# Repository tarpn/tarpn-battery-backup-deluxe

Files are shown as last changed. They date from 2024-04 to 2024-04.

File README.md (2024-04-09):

# TARPN Battery Backup Deluxe

An open source DC-DC Uninterrupted Power Supply for TARPN. 

📖 Click here for [Operation Manual](https://github.com/tarpn/tarpn-battery-backup-deluxe/wiki/Operation-Manual) 📖

Battery Backup Deluxe (BBD) is a system that monitors and switches DC power between a 
power supply and a battery. It is a bespoke power management solution for multi-port packet
radio nodes in the [TARPN project](http://tarpn.net). It is also generally useful for any 12V
systems including non-TARPN Amateur Radio activities.

Supported Features:
* High current capability (30A continuous)
* Automatic switchover to battery
* Battery protection (low/high voltage cutoff)
* Over-temperature cutoff
* Separate switching of critical loads power for priority devices (3A max)
* Safe shutdown procedure of RaspberryPi

Experimental Features:
* Battery charging

Non-Features:
* Load distribution or fusing
* Integration with battery chargers (AC/DC chargers, or solar charge controllers)

Two custom PCBs are employed for voltage sensing, switching, and control. The two boards are
referred to as the Power Board and the Control Board. The Power Board connects to a regulated
DC power supply, a 12V battery, a 12V load, a DC buck regulator for a RaspberryPi, and the Control Board. 
The Control Board connects to a RaspberryPi using a communication cable. 

# Images

Power Board, bare PCB
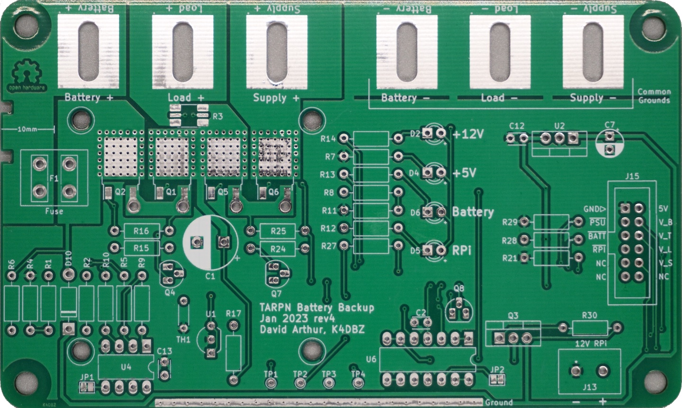
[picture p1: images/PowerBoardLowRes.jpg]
Power Board PCB


Power Board, assembled and installed



# PCB Overview

Power board layout

```
 -[B]--[L]--[S]--[N]--[N]--[N]-
|  |    |    |                 |
|  |~S2~ ~S1~               [C]|
|  |                           |
|   ~ ~ ~ ~ ~ ~ ~ ~ ~ ~ S3     |
|                        |     |
 -----------------------[P][N]-
```

Labels:

* B: Battery Positive
* S: Supply Positive
* L: Load Positive
* N: Common Grounds
* P: Critical Load Positive
* S1: Supply Switch
* S2: Battery Switch
* S3: Critical Load Switch
* C: 12-pin connector to control board

Three p-channel mosfet switches are utilized to connect various loads to one of two DC power sources. 
Loads connected to the "L" terminal are either connected to the Power Supply "S" via S1, the Battery 
"B" via S2, or they are disconnected. A separate low power switch S3 is used for critical loads, 
such as a RaspberryPi or other low power control circuits.

S1 and S2 are high powered DPAK mosfets with a very low on-resistance.

All connected supplies and loads share a common ground. This ground is also shared with the control board. 
If a RaspberryPi (or other device) is monitoring the serial output of the control board, it must also share
this common ground.

Control board layout

```
 ------------------------------
|         ___________      ___  |
|[C]     |   OLED    |    | R | |
|         -----------      ---  |
|    [RPi]               [ICSP] |
 ------------------------------
```

Labels:

* C: 12-pin connector to power board
* RPi: 10-pin connector to Raspberry Pi
* ICSP: Programming header for ATMega
* OLED: 128x32 OLED display
* R: Rotary encoder with switch

# Control Board Modes

The digital electronics on the power board, the 5V regulator for the Control Board, and the critical load
output are powered directly by the battery. 

## Standby

When a power supply is attached and supplying a sufficient voltage, the system will be in Standby mode. 
Loads are powered by the power supply through S1.

* S1: closed
* S2: open
* S3: closed

## Backup

If a low voltage is detected on the power supply, the loads are transferred to the battery. This switching
time is typically in the microsecond range. The ability of the loads to maintain sufficient voltage during
the switching time is dependent on the load current and the available standby capacitance. 
C1 on the power board can be populated with a reasonably large (1000µF range) bulk capacitor. 

* S1: open 
* S2: closed
* S3: closed

## Recovery

Once in the Backup state, the system will enter the Recovery state if a sufficient voltage is seen at the
power supply input. To avoid oscillations, the system will remain in the Recovery state for a configured
number of milliseconds before transitioning to Standby.

* S1: open 
* S2: closed
* S3: closed

## Faults

The system monitors battery voltage to protect the loads from over-voltage and to protect the battery from
under-voltage. In these two cases, the battery is disconnected from the loads.

A temperature sensor is used to monitor the temperature of the PCB near the mosfet switches. If a high
temperature is detected, the switches are both opened to prevent the mosfets from over-heating and failing.

* S1: open 
* S2: open
* S3: closed

# Tuning

To account for variability of components used by the sensor circuits, the firmware includes several "tunables".

* X1: Current Sense. A scaling factor for the current shunt resistor R3. It should be set to 0.04 (20 * R3)
* X2: Current Offset. A voltage offset provided by the reference voltage U1. It should be set to 2.486
* X3: ADC Reference. A voltage reference provided by U5. Measured from AREF (typically 4.860)
* X4: Voltage Factor. A scaling factor for the two resistor divider networks R1+R4 and R8+R11. It should be set to R4 / (R1 + R4).
* X5: Voltage Offset. A voltage offset for the resistor divider networks. Set this to 0.0
* X6: Battery Factor. The same as X1, but for R36 (this may be deprecated in the future)
* X7: Battery Offset. The same as X2, but for the battery current shunt (this may be deprecated in the future)

# Configuration

TODO

# RaspberryPi Interface

J8 on the control board connects to pins 1 through 10 on the RaspberryPi. 

| Pin | RPi signal | Control board signal |
| --- | --- | --- |
| 1 | +3V3 | used for pullup of pin 5 |
| 2 | +5V | unused |
| 3 | GPIO 2 | RPI_PWR (active low) |
| 4 | +5V | unused |
| 5 | GPIO 3 | RPI_SHUTDOWN (active low) |
| 6 | Ground | Ground |
| 7 | GPIO 4 | Reset† |
| 8 | GPIO 14 | RXD (serial) |
| 9 | Ground | Ground |
| 10  | GPIO 15 | TXD (serial) |

† This pin is sometimes cut on older TARPN installations. See below for workaround instructions.

The RPI_SHUTDOWN signal is used to trigger a shutdown of the RPi. When this signal is momentarily pulled low the RPi 
will perform a safe shutdown. A pull-up resistor between RPi pin 5 and RPi pin 1 is used to prevent this
signal from floating.

The RPI_PWR is used to inform the control board whether or not the RPi has power. When this signal is
low, the RPi is powered on. This signal allows the control board to determine when the RPi has powered off 
following a safe shutdown.

RXD and TXD are used for serial communication from the control board to the RPi. This is used for exporting
telemetry from the control board.

If pin 7 has been cut, a separate jumper between an unused GPIO on the RPi and the RESET line on the control 
board will be needed. Pin 5 of the ISCP header can be used to solder one end of a jumper. When doing firmware
uploads from the RPi, a different reset pin can be selected with the `--gpio` argument.

## RPi Hardware Modification

To accommodate the 10 pin ribbon connector on the RPi, pins 11 and 12 must be snipped or bent out of the way.



## RPi Hardware Configuration

To enable the functions of RPI_SHUTDOWN and RPI_PWR, two special configurations are needed on the RPi.
In the `/boot/config.txt` file, add the following lines below the comment 
`# Additional overlays and parameters are documented /boot/overlays/README`:

```
dtoverlay=gpio-poweroff,gpiopin=2,active_low=1
dtoverlay=gpio-shutdown,gpio_pin=3,active_low=1,gpio_pull=up
```

The hardward UART must also be enabled for communication with the control board. At the bottom of `/boot/config.txt`, add

```
[all]
enable_uart=1
```

This can be done when preparing the SD card or on a running RPi. If done on a running RPi, a reboot is necessary for the 
changes to take affect.

## RPi Software Setup

Assuming a starting point of Raspberry Pi OS (Debian Bullseye or Bookworm), we need to install a few dependencies.

```
sudo apt-get -y install python3-pip python3-venv supervisor prometheus prometheus-node-exporter lsof avrdude
```

Configure supervisor to be run as the "pi" user. Modify the file `/etc/supervisor/supervisord.conf` to add a "chown"
to the "unix_http_server" section:

```
[unix_http_server]
file=/var/run/supervisor.sock   ; (the path to the socket file)
chmod=0700                      ; sockef file mode (default 0700)
chown=pi:pi                     
```

Restart supervisor service
```
sudo service supervisor restart
```

Confirm supervisor is running and accessible

```
supervisorctl pid
```

Should return the PID (Process ID) of the supervisord program.

### Install tarpn-bbd Python package

Create an installation directory under `/opt` and install a Python environment into it.

_These instructions assume an installation directory of /opt/tarpn. However, the software can be installed at any location_

```
sudo mkdir /opt/tarpn
sudo chown pi:pi /opt/tarpn
python3 -m venv /opt/tarpn
```

Install the `tarpn-bbd-agent` program into the newly created Python environment

```
/opt/tarpn/bin/pip install --upgrade --index-url https://pypi.mumrah.synology.me/simple tarpn-bbd-agent
```

This will install the program and create several directories under `/opt/tarpn`. 

### Configure Supervisor

Once the tarpn-bbd Python package is installed, we can copy a supervisor config into the system's
configuration directory. This will allow for the Python program to be automatically run on RPi startup
and automatically restarted if it encounters a fatal error.

```
sudo cp /opt/tarpn/extra/tarpn-bbd-agent-supervisor.conf /etc/supervisor/conf.d/tarpn-bbd-agent.conf
```

This file tells supervisor how to run the tarpn-bbd-agent program. Issue a "reload" command to tell
supervisor to read this new config file

```
supervisorctl reload
```

Now the agent program should be running. Run "supervisorctl status" to confirm. The output should look like:

```
> supervisorctl status
tarpn-bbd-agent                  RUNNING   pid 15487, uptime 0:00:04
```

Check that the metrics are being exposed over HTTP. Visit http://localhost:9000 on the RPi, or http://<your-rpi-ip-address>:9000
from another computer on your network. You should see a plain text output that looks like:

```
# HELP python_gc_objects_collected_total Objects collected during gc
# TYPE python_gc_objects_collected_total counter
python_gc_objects_collected_total{generation="0"} 327.0
python_gc_objects_collected_total{generation="1"} 81.0
python_gc_objects_collected_total{generation="2"} 0.0
```

Next, check that the node metrics are being exposed by the prometheus-node-exporter. Visit http://localhost:9100
or http://<your-rpi-ip-address>:9100. This will have a lot more output than the other exporter. Here is a snippet

```
# HELP node_cpu_seconds_total Seconds the CPUs spent in each mode.
# TYPE node_cpu_seconds_total counter
node_cpu_seconds_total{cpu="0",mode="idle"} 2883.87
node_cpu_seconds_total{cpu="0",mode="iowait"} 5.04
node_cpu_seconds_total{cpu="0",mode="irq"} 0
node_cpu_seconds_total{cpu="0",mode="nice"} 0
node_cpu_seconds_total{cpu="0",mode="softirq"} 0.95
node_cpu_seconds_total{cpu="0",mode="steal"} 0t
node_cpu_seconds_total{cpu="0",mode="system"} 11.35
node_cpu_seconds_total{cpu="0",mode="user"} 22.08
```

### Python Configuration

The default configuration should work on most installations, but if a different serial port or HTTP port is needed, 
it can be changed in `/opt/tarpn/config/bbd.ini`

```
[default]
log.dir = /opt/tarpn/logs
log.config = config/logging.ini
serial.port = /dev/ttyS0
serial.speed = 38400
prometheus.port = 9000
```

After re-configuring, restart the service with supervisor

```
supervisorctl restart tarpn-bbd-agent
```

# Monitoring

If desired, a metrics collection database (Prometheus) and dashboard system (Grafana) can be used to visualize
the sensor data exported by the control board.

Prometheus needs network access to the RPi running `tarpn-bbd`, and Grafana needs network access to Prometheus.
On a home network, this is usually achieved without any extra effort. It is possible to run the TARPN stack 
(including `tarpn-bbd`) along with Prometheus and Grafana, but it is also possible to run Prometheus and Grafana
on a separate server if resources of the RPi become constained.

## Prometheus Configuration

Prometheus is an efficient time-series database that is optimized for metrics collection. By default, Prometheus 
is installed on the RPi that is also running TARPN and the Python agent. If desired, Prometheus can also be 
installed on another server (RPi or otherwise). Follow the 
[general installation instructions](https://prometheus.io/docs/prometheus/latest/installation/) for this.

Put the prometheus config in place

```
sudo cp /opt/tarpn/extra/prometheus.yml /etc/prometheus/prometheus.yml
```

And restart prometheus

```
sudo service prometheus restart
```

Launch the Prometheus UI and confirm the three targets are "UP". Load the UI by accessing http://localhost:9090 
on a web browser on the RPi, or http://<your-rpi-ip-address>:9090 from a web browser on another computer in your
network.

Click on Status, then Targets



And the three Targets should be in the "UP" State.



## Grafana Install and Configuration

Follow the instructions to [install Grafana OSS](https://grafana.com/tutorials/install-grafana-on-raspberry-pi/#install-grafana).
Grafana can run on the TARPN RPi or on a separate server (RPi or otherwise).

For other installation types, follow the [general installation instructions](https://grafana.com/docs/grafana/latest/setup-grafana/installation/).

Copy some configuration files from the `tarpn-bbd` installation over to Grafana

```
sudo cp /opt/tarpn/extra/grafana.ini /etc/grafana/grafana.ini
sudo cp /opt/tarpn/extra/prometheus-datasource.yml /etc/grafana/provisioning/datasources/prometheus.yml
```

Enable Grafana service (as indicated the Grafana installation output). This will enable Grafana to start
when the RPi starts.

```
sudo /bin/systemctl daemon-reload
sudo /bin/systemctl enable grafana-server
```

Start Grafana (restart if it's already running)
```
sudo service grafana restart
```

Access the Grafana UI at http://localhost:3000 or `http://<your-rpi-ip-address>:3000`. 



Confirm the "prometheus" datasource was created

https://github.com/tarpn/tarpn-battery-backup-deluxe/assets/55116/4cb37a2d-a11b-4c16-b97d-481c0bf3d614

Next, import the dashboard

* Open https://github.com/tarpn/tarpn-battery-backup-deluxe/blob/main/py/extra/grafana-dashboard.json
* Click "Download Raw File"
* Open Grafana UI
* Navigate to Dashboards
* Click New -> Import
* Select the dashboard JSON file
* Select the "Prometheus" datasource we looked at earlier

https://github.com/tarpn/tarpn-battery-backup-deluxe/assets/55116/16305afa-259e-4ca9-8b7f-3a017b2bc0ff

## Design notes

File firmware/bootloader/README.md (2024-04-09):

Built from optiboot at revision 55d1e6b36922

```
make clean AVR_FREQ=8000000 BAUD_RATE=38400 LED=D7 LED_START_FLASHES=3 LED_DATA_FLASH=1 UART=0 TIMEOUT=4 atmega328
```

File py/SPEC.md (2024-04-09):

Serial data specification for BBD firmware

v1 Sep 14, 2023
===============

On firmware startup, the string "START" is sent followed by a newline.

Subsequently, every 2 seconds or when a event occurs, the firmware will send data in the 
following BNF form:

```
<line>		::= <state> <ws> "Battery=" <float> <ws> "Supply=" <float> <ws> "RPiOn=" <bool> <ws> "StateTime=" <long> <ws> "UpTime=" <long> <ws> "DT=" <long> <ws> "Git=" <str> [<cont>] <nl>
<ws>		::= " " [<ws>]	; any amount of whitespace characters
<nl>		::= "\n"	; newline character
<float>		::= <digits> "." <digits>
<long>		::= <digits>
<bool>		::= "1" | "0"
<str>		::= <letter> [<str>]
<digits>	::= <digit> [<digits>]
<state>		::= "Null" | "Initializing" | "Standby" | "Backup" | "Recovery" | "BatteryLow" | "BatteryLowTrip" | "BatteryHigh" | "BatteryHighTrip" | "OverTemp" | "OverTempRecovery" | "BeginShutdown" | "RPiShutdown" | "ShutdownComplete"
<cont>		::= <ws> "Temperature=" <float> <ws> "AH=" <float> <ws> "AmpSecDelta=" <float> <ws> "BatteryAmpSec=" <float> <ws> "AmpAvg=" <float> <ws> "AmpMax=" <float> <ws> "WattSecDelta=" <float> "<ws>WattAvg=" <float>
```

v2 Dec 26, 2023
===============

Serial data is ascii text separated by newlines. The first word of a line indicates its type.

Previously, each line was interpreted as metrics data with the exception of a special "START" line. Now, each line 
will begin with its message type allowing for more flexibility in the protocol.

Three types will be defined initially

* `DATA`: a line of key/value data pairs. See format below
* `EVENT <type> [<args>]`: a discrete event that occurred, such as a switch changing states
* `LOG`: informational text sent by the firmware

Also, this version of the protocol introduces bidirectional communication. 

* `P <0|1> <len> <text>`: informational text sent by the PC for display by the OLED. One of two lines is specified followed 
                           by the desired text. Any characters exceeding the width of the display will be truncated
* `H`: a heartbeat, sent periodically to inform the firmware that the PC is alive

Change state strings to be all caps with underscores. This is to align the state with the new UI
for the OLED display.

```
<line>		::= <state> <ws> "Battery=" <float> <ws> "Supply=" <float> <ws> "RPiOn=" <bool> <ws> "StateTime=" <long> <ws> "UpTime=" <long> <ws> "DT=" <long> <ws> "Git=" <str> [<cont>] <nl>
<ws>		::= " " [<ws>]	; any amount of whitespace characters
<nl>		::= "\n"	; newline character
<float>		::= <digits> "." <digits>
<long>		::= <digits>
<bool>		::= "1" | "0"
<str>		::= <letter> [<str>]
<digits>	::= <digit> [<digits>]
<state>		::= "NULL" | "INITIALIZING" | "STANDBY" | "BACKUP" | "RECOVERY" | "BATT_LOW" | "BATT_LOW_TRIP" | "BATT_HIGH" | "BATT_HIGH_TRIP" | "OVER_TEMP" | "OVER_TEMP_RECOVER" | "BEGIN_SHUTDOWN" | "RPI_SHUTDOWN" | "SHUTDOWN_COMPLETE"
<cont>		::= <ws> "Temperature=" <float> <ws> "AH=" <float> <ws> "AmpSecDelta=" <float> <ws> "BatteryAmpSec=" <float> <ws> "AmpAvg=" <float> <ws> "AmpMax=" <float> <ws> "WattSecDelta=" <float> "<ws>WattAvg=" <float>
```

##  Metrics Flow

### Current

Shows "instantaneous" current. 

Prometheus metrics: load_amps, peak_amps

load_amps: Gauge, set by AmpAvg from serial
peak_amps: Gauge, set by AmpMax from serial

AmpAvg is the number of accumulated amp-seconds divided by the reporting period. Amp-seconds are 
continuously integrated whenever the ADC is sampled.

### Power

Shows "instantaneous" power (watts).

Prometheus metric: load_watt, load_watt_sec

load_watt: Gauge, set by WattAvg from serial
load_watt_sec: Counter, incremented by WattSecDelta from serial

WattAvg is accumulated watt-seconds divided by the reporting period. The watt-seconds are
continuous integrated as (current * voltage) whenever the ADC is sampled. This gives more accurate
reading since the voltage can vary based on the current.

WattSecDelta is the number of watt-seconds accumulated during the reporting period.

```
metrics->report->load_amp_sec_delta = (metrics->current_amp_seconds - metrics->report->load_amp_sec);
metrics->report->load_amp_sec = metrics->current_amp_seconds;
metrics->report->load_amp_avg = metrics->report->load_amp_sec_delta / report_period_s;
```

TODO

* Instantaneous Battery Voltage, Current. 
* Instantaneous Load Power (computed based on state)
* Delta of power. Watt*sec since last report. `increase(load_watt_sec_total[1m]) / 60`
* Cumulative power? Watt*sec since startup. Is this useful? Why not just sum the delta

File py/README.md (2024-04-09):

# Python Metrics Scraper

# Installation

## System Requirements

On Linux (including Raspbian) ensure at least Python 3.7 is installed.

```shell
python3 --version
```

Next, install pip, and virtualenv

```shell
sudo apt-get install python3-pip
pip3 install virtualenv
```

On Mac OS:

```shell
brew install python3
pip3 install virtualenv
```

## Install the software (RPi)

Create an installation directory under opt and install a Python environment into it

_These instructions assume an installation directory of /opt/tarpn. However, the software can be installed at any location_

```shell
sudo mkdir /opt/tarpn
sudo chown pi:pi /opt/tarpn
python3 -m venv /opt/tarpn
```

Install a release

```shell
/opt/tarpn/bin/pip install --upgrade --index-url https://pypi.mumrah.synology.me/simple tarpn-bbd-agent
```

## Configuration

A sample config file is provided in /opt/tarpn/config/bdd.ini.sample

```ini
; Do not edit this file. Make a copy named bdd.ini and edit that one.

[default]
log.dir = /opt/tarpn/logs
log.config = config/logging.ini
serial.port = /dev/ttyS0
serial.speed = 38400
prometheus.port = 9000
```

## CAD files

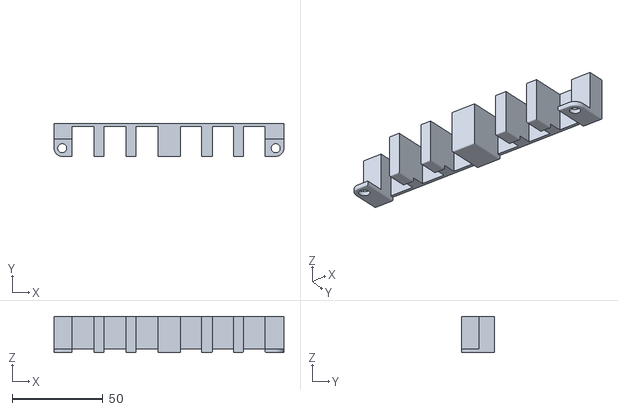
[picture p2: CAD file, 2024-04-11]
3d-models/TerminalGuard.stl
126.4 x 18.0 x 20.0

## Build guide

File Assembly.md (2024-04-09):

# Assembly

Required tools:
* Temperature controlled soldering station (e.g., Hakko FX888D, Weller WLC100)
* Hot air rework station
* Precision tweezers
* Silicone work mat
* Fume extractor (recommended)

Several assembly steps for the Power Board require very high heat. A silicone mat may be required to protect your work surface. 
Be careful handling the PCB in between assembly steps.

The general sequence of assembly for the Power Board is according to height. Shorter parts are assembled first.

* SMD parts 🔥
  * R3
  * Q1, Q2, Q5, Q6
  * Q1 to Q2 jumper (optional)
  * Q5 to Q6 jumper (optional)
* Resistors, diodes, thermistor, ceramic capacitors
* RN1
* U7, U6, U4 (optionally, sockets for each)
* D2, D4, D5, D6 (LEDs)
* TO-92 parts
* J12 (12 pin connector)
* J13 (Terminal screw block)
* 12V fan connector
* C7, C1 (electrolytic capactitors)
* Terminal Lugs 🔥
* F1 connectors 🔥
* U2, Q3 (TO-220)
* Heat sink (optional)

## BOM

The Bill-Of-Materials for Digi-Key is located at this address https://www.digikey.com/en/mylists/list/4BDBKJ7A9E. There are two
optional parts in the BOM (heatsink and push-pins) with quantity zero.

Some additional parts will need to be sourced from other vendors.

* Six (6) Terminal Lugs, part number B6A-PCB-RS from [LugsDirect](https://lugsdirect.com/IHI_HIGH_CURRENT_PCB-TERMINALS-_SELECTION_CHART2.htm)
* i2c 128x32 OLED Display, Amazon/eBay/etc. [Example Amazon Listing](https://www.amazon.com/Pieces-Display-Module-SSD1306-3-3V-5V/dp/B08L7QW7SR) 
* 12 pin rectangular ribbon connector [Example Amazon listing](https://www.amazon.com/gp/product/B07FKPXML5)

Optional parts:
* IC sockets [Example Amazon listing](https://www.amazon.com/Glarks-122Pcs-Sockets-Adaptor-Assortment/dp/B01GOLSUAU)
* 12V fan (in BOM)
* Heatsink (in BOM)
* Large thermal pad for heatsink [Example Amazon listing](https://www.amazon.com/gp/product/B09DC772PR)

## SMD Resistor (R3) soldering

🔥Hot Parts🔥

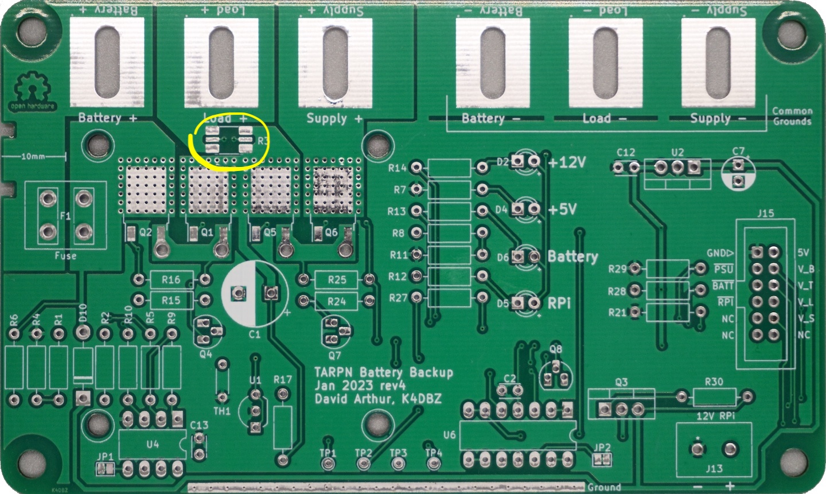
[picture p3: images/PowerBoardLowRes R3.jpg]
R3


This resistor is essentially a chunk of copper with specific dimensions to give a good precision small resistance.
For best results, this part should be soldered to the four pads of the footprint as evenly as possible. For best
results, pre-solder a very small amount of solder to the four pads and clean them with IPA or flux remover. Visually
inspect them to see that they are around the same height. Place the SMD resistor on the pads and apply hot air.

## DPAK soldering

🔥Hot Parts🔥

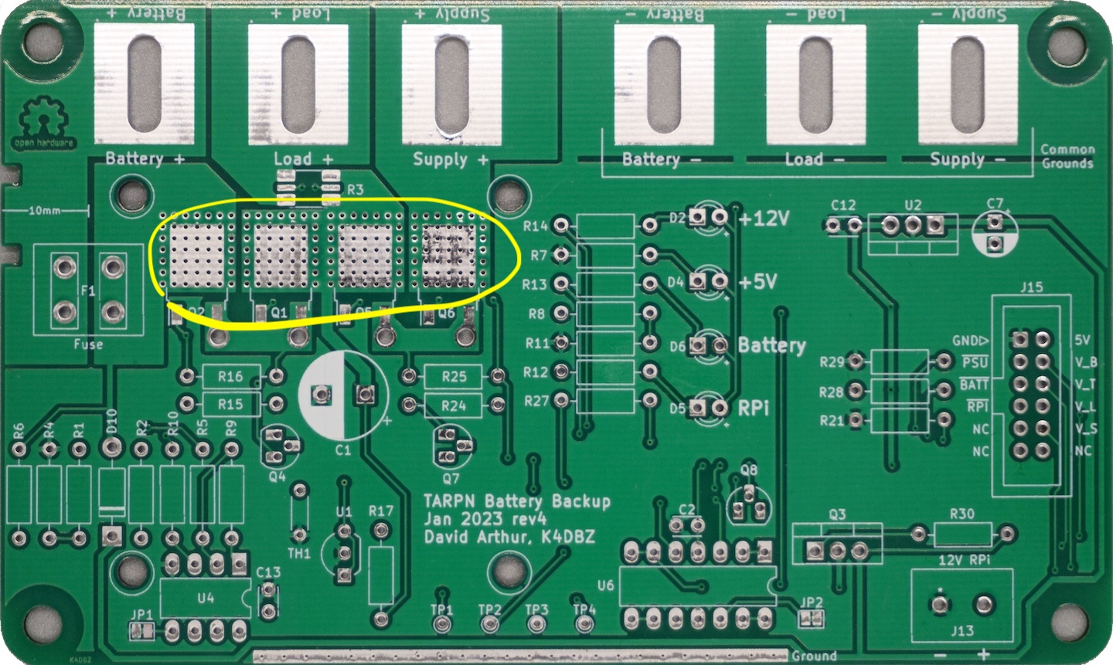
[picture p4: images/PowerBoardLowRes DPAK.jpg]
DPAK Mosfets


The four DPAK mosfet are best soldered with a high temperature (750-800F) iron with a large tip. Hot air can be useful as well.

The big pad should be pre-soldered and cleaned with alcohol or other flux remover. The solder will wick through
the thermal vias during pre-soldering, this is normal. After pre-soldering, apply flux to the pad and solder the
two legs. Once the legs are soldered, begin applying heat to the pad and tab. 

The Power Board has a copper plane on the top and bottom, and the mosfet pads are connected through to the back
with thermal vias. It will take some time for the board to heat up sufficiently for solder to flow. Once the 
existing solder starts to flow, apply fresh solder until adequate fillets are present all around the tab.

## Mosfet jumpers

🔥Hot Parts🔥

Two copper jumpers can be installed to improve the ampacity of the Power Board. A gauge is provided on the edge of the
Power Board to help form the jumpers. The jumper holes are 2.6mm which will accommodate 10 AWG wire. If the jumper is
installed, apply enough solder to create a fillet between the jumper and the mosfet leg.

## Resistors

Some of the resistors on the power board are high precision (0.1%)

* 49.9 kOhm: R1,R6,R8
* 10 kOhm: R2,R4,R9,R11
* 259 Ohm: R5,R10

These are mainly used as high precision voltage divider for accurate sensing of the temperature, voltage, and current.

The remaining resistors on the power board are pull-ups, pull-downs, and current limiting resistors. These are 5% precision
resistors.

* 1 kOhm: R15, R17, R24, R27
* 10 kOhm: R16, R21, R25, R28, R29, R30

## Diodes

* D10
* D1

There are two diodes on the power board. They are different part numbers, so be careful not to mix them up. D10 is a 
general recitfier diode, and D1 is a flyback diode for the fan.

## Thermistor

Install TH1. Try to ensure the part is flush with the board so it can accurately read the temperature of the PCB.

## Ceramic Capacitors

Install the 0.1µF ceramic capators: C2, C12, C13

## Resistor Network RN1

Install RN1. This resistor network is used by the status LEDs.

## Integrated Circuits

There are three ICs on the power board. Two of them (U6 and U7) have the same footprint, but are different parts. IC sockets 
can optionally be installed at this point.

## LEDs

There are four status LEDs on this board. The three green LEDs are for +12V, +5V, and RPi. The yellow LED is for Battery.
The long leg of the resistor goes on the right where the small "+" symbol is printed.

## TO-92 packages

There are four TO-92 parts. Three of them (Q4, Q7, Q8) are the same transistor and one is a precision voltage regulator (U1). 
The three transistors are used to drive power mosfets which are used for 12V switching. The voltage regulator is used
to provide a precise voltage to U4 in order to get accurate current sensing.

## 12V Connectors

Two connectors on the board provide 12V that can be switched off under low power conditions. These are used to power an 
offboard DROK (or other buck converter) used by the RPi and to power an optional fan for cooling. 



## Electrolytic Capacitors

Install C7 and C1.

## Terminal Lugs

🔥Hot Parts🔥

The six terminal lugs are designed to be wave soldered, but hand soldering is also possible. These parts require
the most heat of any in the assembly, so take care when handling the PCB during this step. Since these lugs are so
large, it is necessary to place some supporting material under the PCB in order to balance it and keep it level. Scrap
silicone work mat works nicely for this
 
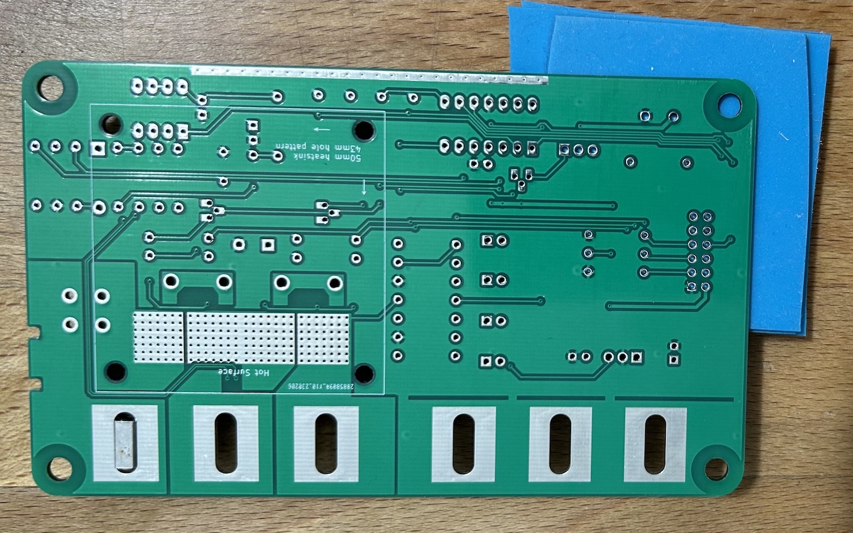
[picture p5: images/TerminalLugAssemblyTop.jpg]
Terminal Lug Assembly Top


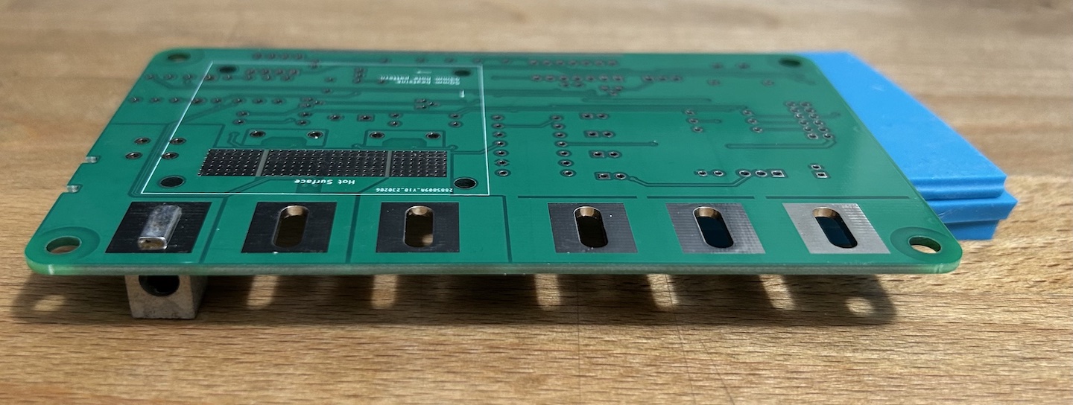
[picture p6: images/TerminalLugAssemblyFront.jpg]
Terminal Lug Assembly Front


Remove the bolts from the lugs and place one of them upside down on the work surface. Balance the PCB on top of it using
some supporting material as pictured above. Heat the soldering iron to 800-850F and apply some solder to the tip. 
Begin heating the terminal lug. This will take some time. Once the solder starts to transfer from the iron tip to the 
lug surface, begin heating the pad on the PCB. The terminal lug has very high thermal mass and will
stay hot for a long time after pre-heating. Once solder begins to flow on the pad, apply around 30mm of solder (roughly
three times the length of the pad). Drag the solder around the all edges where the terminal contacts the PCB. There should
be enough solder to form a nice fillet along the two long edges of the terminal and to fill the gaps on either end.

Repeat the process for the remaining 5 lugs.

Once the terminals and PCB have cooled enough to handle, clean the pads with IPA or flux cleaner. 

Here are some close-ups showing an acceptable solder joint for a terminal lug:

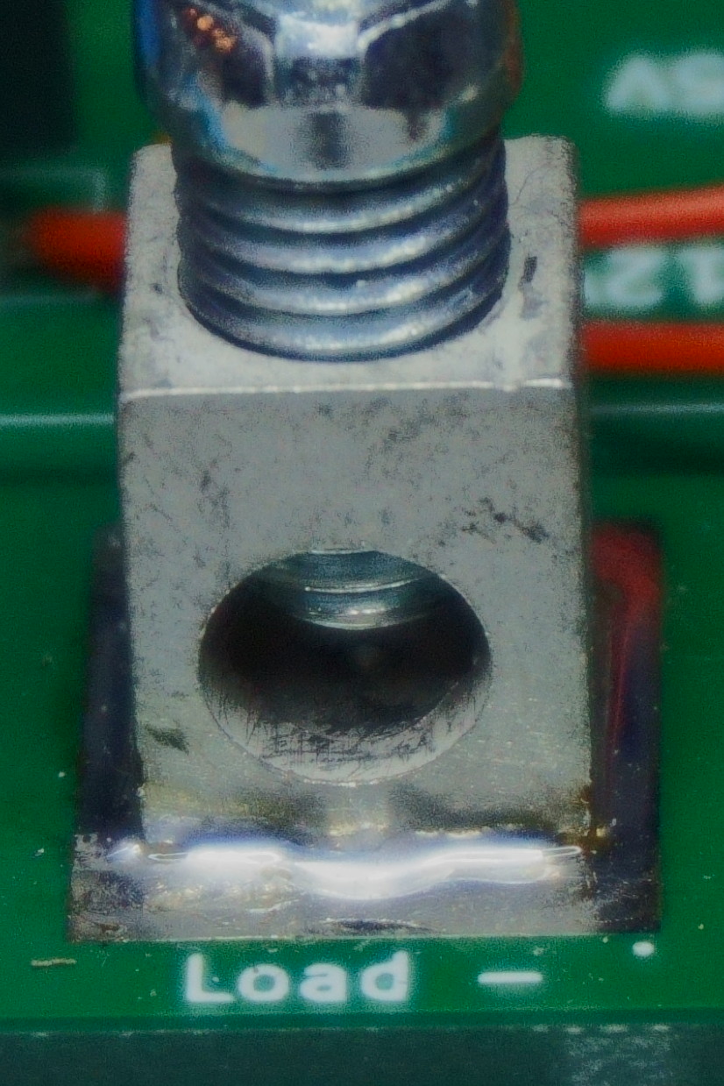
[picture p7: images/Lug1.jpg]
Terminal Lug Close-up 1

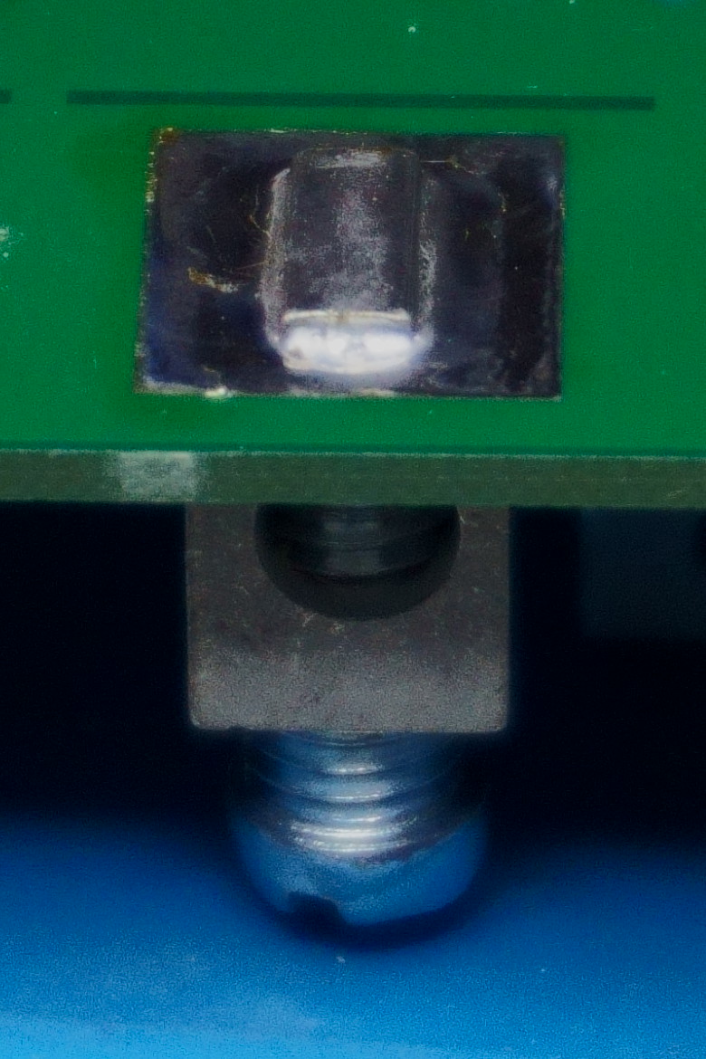
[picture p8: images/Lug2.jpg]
Terminal Lug Close-up 2

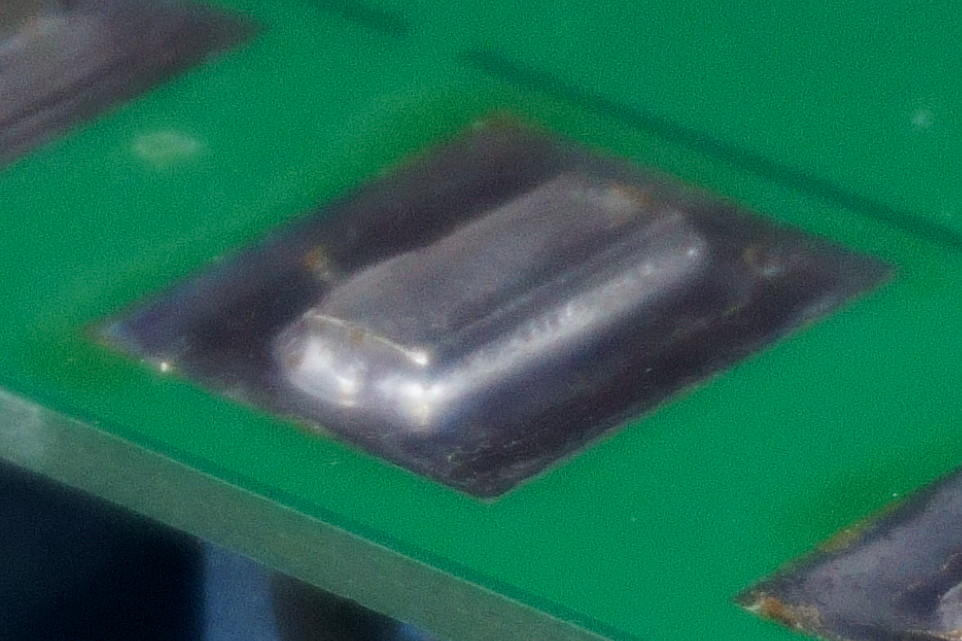
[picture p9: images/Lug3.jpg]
Terminal Lug Close-up 3

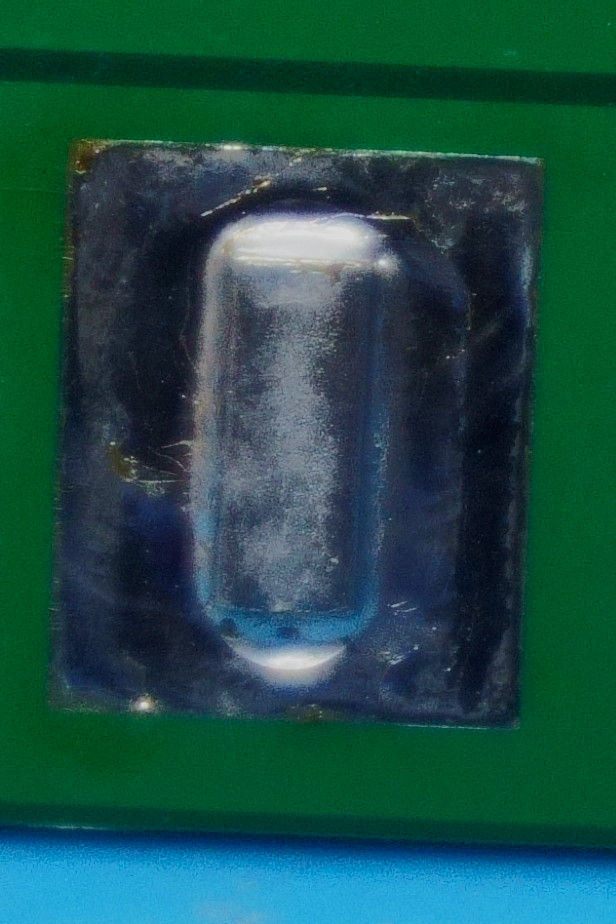
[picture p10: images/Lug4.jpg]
Terminal Lug Close-up 4


## Fuse (F1)

🔥Hot Parts🔥

The F1 fuse footprint accepts two quick connect terminals. Insert the terminals on the top of the PCB according to the
silkscreen and tack them into place from the top. This will secure the terminals well enough to fully solder from the bottom.
When soldering, start on the pin that wasn't tacked from the top.  

## TO-220 parts

There are two TO-220 parts which look the same, but are different parts. U2 is a voltage regular and Q3 is a power mosfet. 
Take care to not mix them up, also take care to install them in the correct orientation.



## Heatsink

To accommodate high current installations, the Power Board has mounting holes for a 50mm square heatsink. 
The hole pattern is 43mm by 43mm on center.

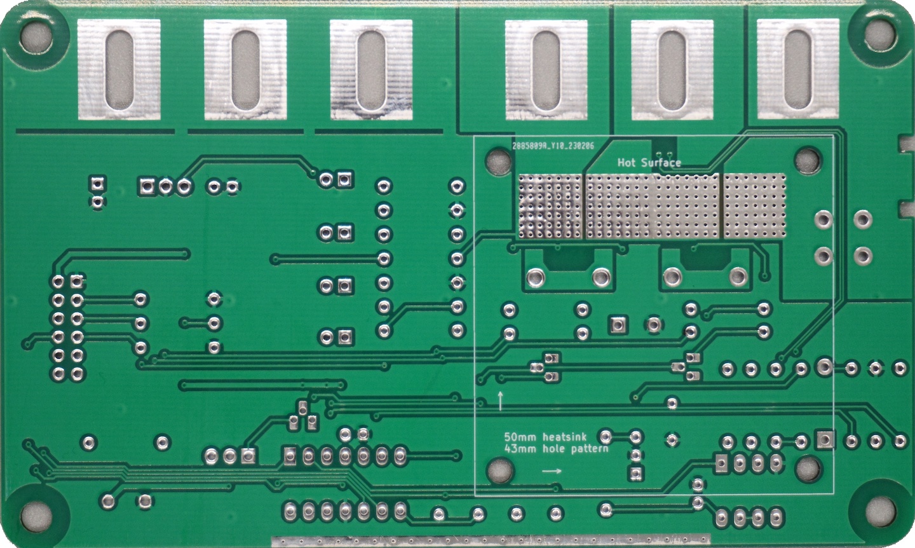
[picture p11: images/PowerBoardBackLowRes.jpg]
Power Board Back


This mounting pattern will accommodate any of the 50x50mm pushPIN™ Heat Sink series from Advanced Thermal Solutions, Inc.
One such heatsink is included in the BOM (with a quantity of zero). If ordering a heat sink, be sure to also order two
units of the push pins. Each unit of push pins includes two pins, so two units gives the requisite four push pins.

Since the back of the PCB has exposed copper, a thermal pad is required to avoid shorting the mosfets with the 
heat sink. Also, since the heatsink area includes many through-hole pads, the thermal pad must be thick enough
to keep the heatsink flat. A pad of at least 1mm thickness is needed. The leads of the through-hole parts in the
heatsink area should be trimmed flush with the solder fillet (not flush with the board). Trimming the leads will
avoid having their sharp ends exposed which could pierce the thermal pad and contact the heatsink.

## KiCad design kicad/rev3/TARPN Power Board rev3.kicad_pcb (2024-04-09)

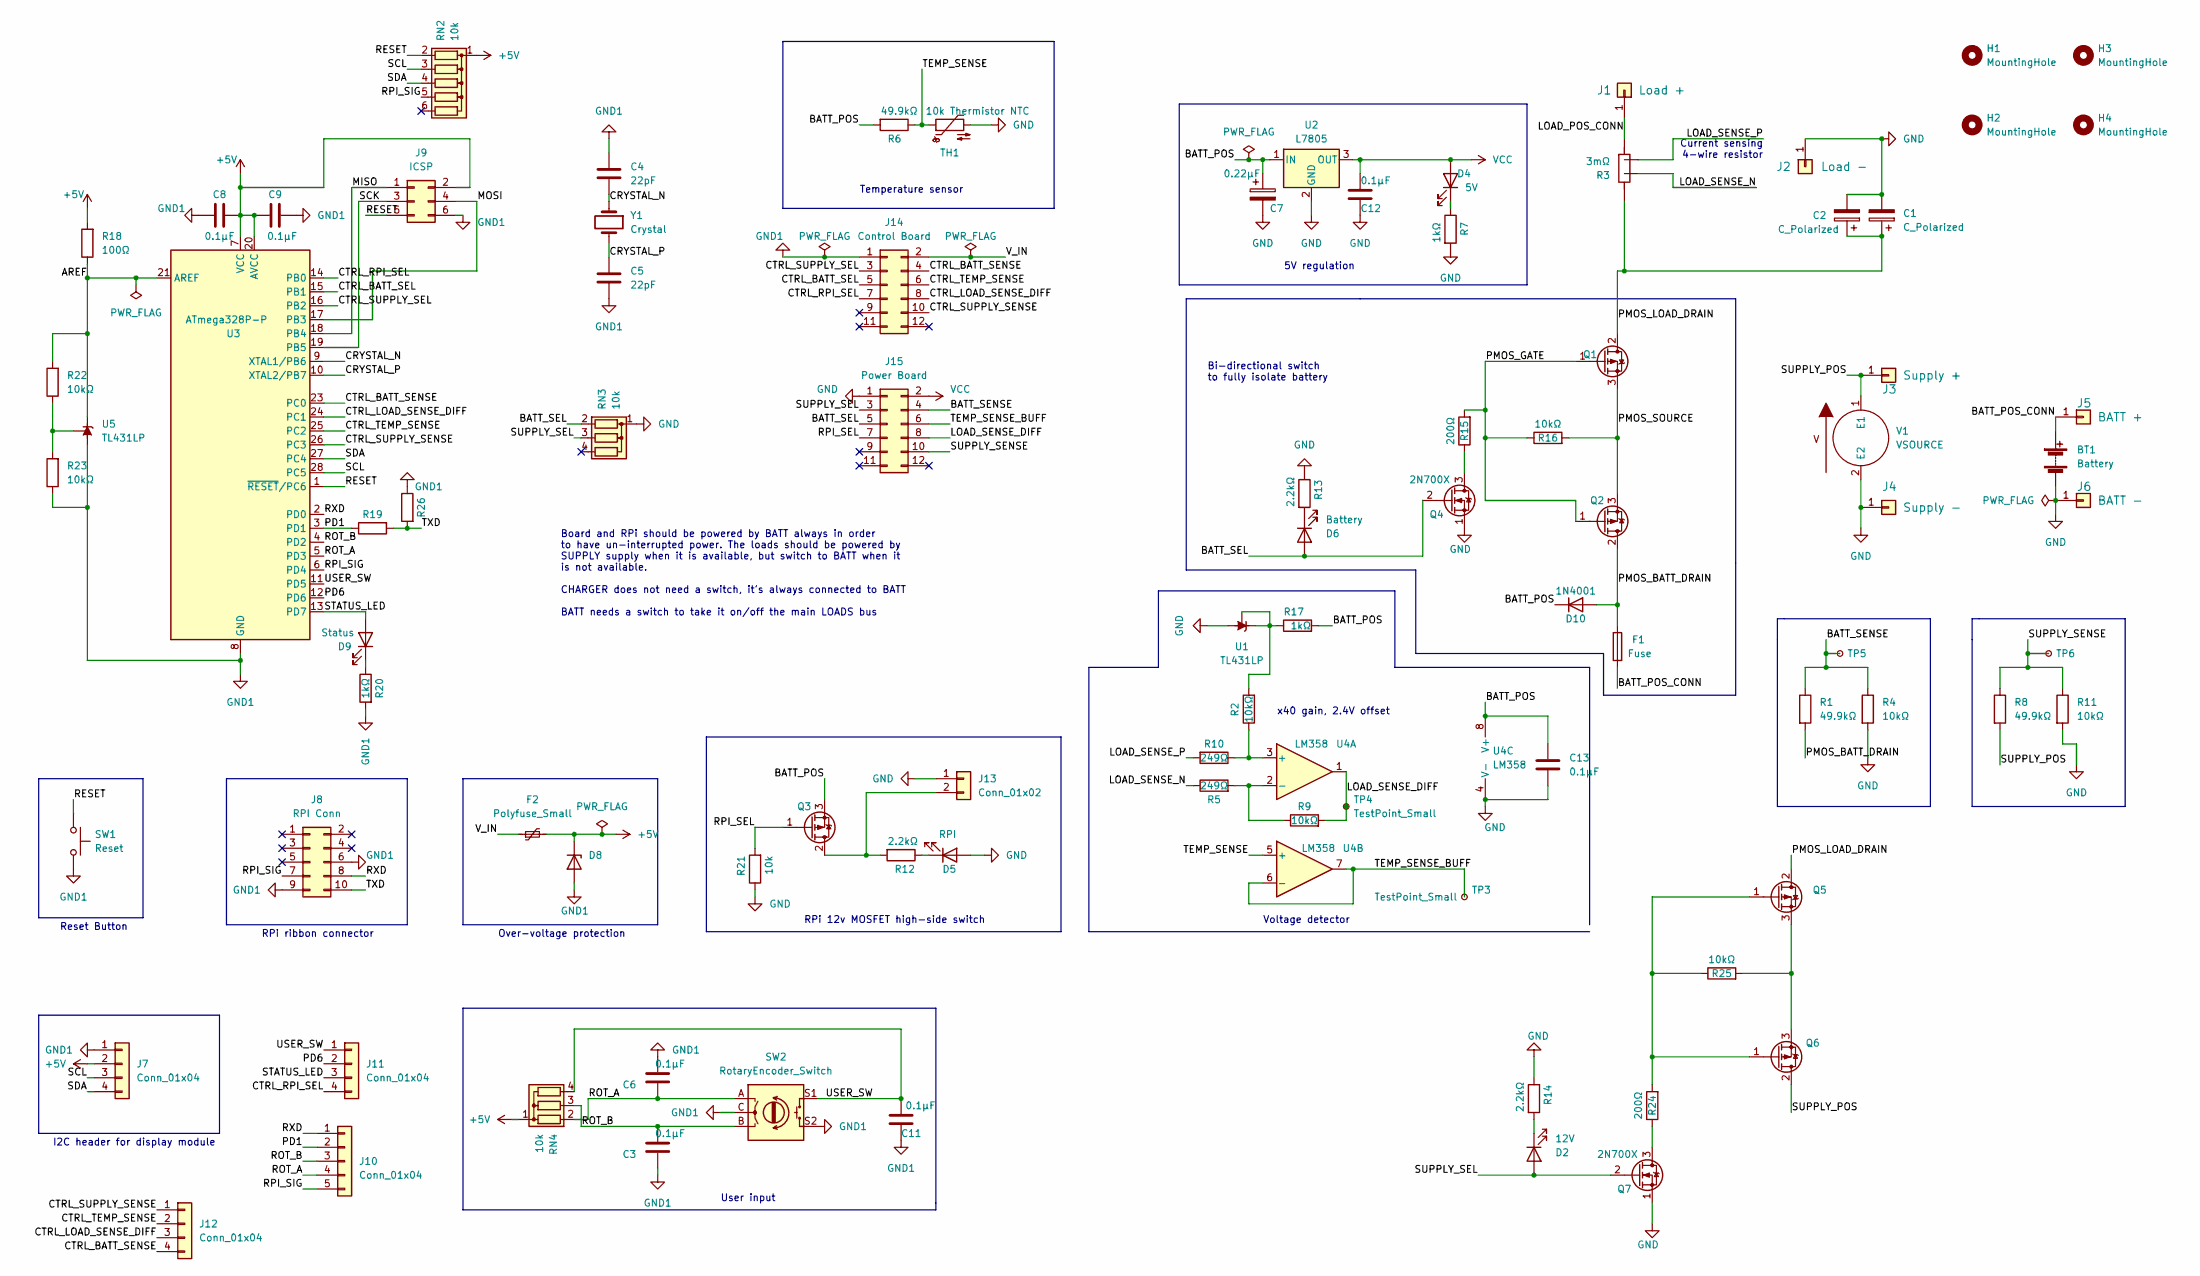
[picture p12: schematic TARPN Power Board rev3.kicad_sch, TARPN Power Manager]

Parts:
BT1: Battery
C1, C2: C_Polarized; CP_Radial_D6.3mm_P2.50mm
C3, C6, C8, C9, C11, C12, C13: 0.1µF; C_Disc_D3.0mm_W2.0mm_P2.50mm
C4, C5: 22pF; C_Disc_D3.0mm_W2.0mm_P2.50mm
C7: 0.22µF; CP_Radial_D5.0mm_P2.50mm
D2: 12V; LED_D3.0mm
D4: 5V; LED_D3.0mm
D5: RPI; LED_D3.0mm
D6: Battery; LED_D3.0mm
D8: D_DO-41_SOD81_P3.81mm_Vertical_KathodeUp
D9: Status; LED_D3.0mm
D10: 1N4001; D_DO-41_SOD81_P10.16mm_Horizontal
F1: Fuse; JCASE
F2: Polyfuse_Small; Littlefuse RXEF Series
H1, H2, H3, H4: MountingHole; MountingHole_4.3mm_M4
J1: Load +; B6A-PCB-RS
J2: Load -; B6A-PCB-RS
J3: Supply +; B6A-PCB-RS
J4: Supply -; B6A-PCB-RS
J5: BATT +; B6A-PCB-RS
J6: BATT -; B6A-PCB-RS
J7, J11, J12: Conn_01x04; PinHeader_1x04_P2.54mm_Vertical
J8: RPI Conn; PinHeader_2x05_P2.54mm_Vertical
J9: ICSP; IDC-Header_2x03_P2.54mm_Vertical
J10: Conn_01x04; PinHeader_1x05_P2.54mm_Vertical
J13: Conn_01x02; 691213510002
J14: Control Board; IDC-Header_2x06_P2.54mm_Vertical
J15: Power Board; IDC-Header_2x06_P2.54mm_Vertical
Q1, Q2, Q5, Q6: IRF4905; TO-252-2-ViasHandSolder
Q3: IRF9Z24; TO-220-3_Vertical
Q4, Q7: 2N700X; TO-92_HandSolder
R1, R6, R8: 49.9kΩ; R_Axial_DIN0207_L6.3mm_D2.5mm_P10.16mm_Horizontal
R2, R4, R9, R11, R16, R22, R23, R25: 10kΩ; R_Axial_DIN0207_L6.3mm_D2.5mm_P10.16mm_Horizontal
R3: 3mΩ; R_2512_6332_4_wire
R5, R10: 249Ω; R_Axial_DIN0207_L6.3mm_D2.5mm_P10.16mm_Horizontal
R7, R17, R20: 1kΩ; R_Axial_DIN0207_L6.3mm_D2.5mm_P10.16mm_Horizontal
R12, R13, R14: 2.2kΩ; R_Axial_DIN0207_L6.3mm_D2.5mm_P10.16mm_Horizontal
R15, R24: 200Ω; R_Axial_DIN0207_L6.3mm_D2.5mm_P10.16mm_Horizontal
R18: 100Ω; R_Axial_DIN0207_L6.3mm_D2.5mm_P10.16mm_Horizontal
R19, R26: R_Axial_DIN0207_L6.3mm_D2.5mm_P10.16mm_Horizontal
R21: 10k; R_Axial_DIN0207_L6.3mm_D2.5mm_P10.16mm_Horizontal
RN2: 10k; R_Array_SIP6
RN3, RN4: 10k; R_Array_SIP4
SW1: Reset; SW_PUSH_6mm
SW2: RotaryEncoder_Switch; RotaryEncoder_Alps_EC11E-Switch_Vertical_H20mm
TH1: 10k Thermistor NTC; R_Axial_DIN0204_L3.6mm_D1.6mm_P5.08mm_Horizontal
TP3, TP4, TP5, TP6: TestPoint_Small; TestPoint_THTPad_D1.5mm_Drill0.7mm
U1, U5: TL431LP; TO-92_Inline_Wide
U2: L7805; TO-220-3_Vertical
U3: ATmega328P-P; DIP-28_W7.62mm
U4: LM358
V1: VSOURCE
Y1: Crystal; Crystal_HC49-4H_Vertical

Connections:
+5V: C8.1, C9.2, D8.1 (K), F2.2, J7.2, J9.2, R18.2, RN2.1 (common), RN4.1 (common), U3.7 (VCC), U3.20 (AVCC)
/AREF: R18.1, R22.2, U3.21 (AREF), U5.3 (K)
/BATT_POS: C7.1, C13.2, D10.1 (K), Q3.3 (S), R6.2, R17.2, U2.1 (IN), U4.8 (V+)
/BATT_POS_CONN: BT1.1 (+), F1.2, J5.1
/BATT_SEL: D6.2 (A), J15.5, Q4.2 (G), RN3.2 (R1)
/BATT_SENSE: J15.4, R1.1, R4.1, TP5.1
/CRYSTAL_N: C4.2, U3.9 (XTAL1/PB6), Y1.1
/CRYSTAL_P: C5.1, U3.10 (XTAL2/PB7), Y1.2
/CTRL_BATT_SEL: J14.5, U3.15 (PB1)
/CTRL_BATT_SENSE: J12.4, J14.4, U3.23 (PC0)
/CTRL_LOAD_SENSE_DIFF: J12.3, J14.8, U3.24 (PC1)
/CTRL_RPI_SEL: J11.4, J14.7, U3.14 (PB0)
/CTRL_SUPPLY_SEL: J14.3, U3.16 (PB2)
/CTRL_SUPPLY_SENSE: J12.1, J14.10, U3.26 (PC3)
/CTRL_TEMP_SENSE: J12.2, J14.6, U3.25 (PC2)
/LOAD_POS_CONN: J1.1, R3.1
/LOAD_SENSE_DIFF: J15.8, R9.2, TP4.1, U4.1
/LOAD_SENSE_N: R3.4, R5.1
/LOAD_SENSE_P: R3.3, R10.2
/MISO: J9.1, U3.18 (PB4)
/MOSI: J9.4, U3.17 (PB3)
/PD1: J10.2, R19.1, U3.3 (PD1)
/PD6: J11.2, U3.12 (PD6)
/PMOS_BATT_DRAIN: D10.2 (A), F1.1, Q2.2 (D), R1.2
/PMOS_GATE: Q1.1 (G), Q2.1 (G), R15.2, R16.1
/PMOS_LOAD_DRAIN: C1.1, C2.1, Q1.2 (D), Q5.2 (D), R3.2
/PMOS_SOURCE: Q1.3 (S), Q2.3 (S), R16.2
/RESET: J9.5, RN2.2 (R1), SW1.1, U3.1 (~RESET/PC6)
/ROT_A: C6.2, J10.4, RN4.2 (R1), SW2.A, U3.5 (PD3)
/ROT_B: C3.1, J10.3, RN4.3 (R2), SW2.B, U3.4 (PD2)
/RPI_SEL: J15.7, Q3.1 (G), R21.2
/RPI_SIG: J8.7, J10.5, RN2.5 (R4), U3.6 (PD4)
/RXD: J8.8, J10.1, U3.2 (PD0)
/SCK: J9.3, U3.19 (PB5)
/SCL: J7.3, RN2.3 (R2), U3.28 (PC5)
/SDA: J7.4, RN2.4 (R3), U3.27 (PC4)
/STATUS_LED: D9.2 (A), J11.3, U3.13 (PD7)
/SUPPLY_POS: J3.1, Q6.2 (D), R8.2, V1.1 (E1)
/SUPPLY_SEL: D2.2 (A), J15.3, Q7.2 (G), RN3.3 (R2)
/SUPPLY_SENSE: J15.10, R8.1, R11.1, TP6.1
/TEMP_SENSE: R6.1, TH1.1, U4.5 (+)
/TEMP_SENSE_BUFF: J15.6, TP3.1, U4.6 (-), U4.7
/TXD: J8.10, R19.2, R26.2
/USER_SW: C11.1, J11.1, RN4.4 (R3), SW2.S1, U3.11 (PD5)
/V_IN: F2.1, J14.2
GND: BT1.2 (-), C1.2, C2.2, C7.2, C12.1, C13.1, D5.2 (A), J2.1, J4.1, J6.1, J13.1, J15.1, Q4.1 (S), Q7.1 (S), R4.2, R7.2, R11.2, R13.1, R14.1, R21.1, RN3.1 (common), TH1.2, U1.2 (A), U2.2 (GND), U4.4 (V-), V1.2 (E2)
GND1: C3.2, C4.1, C5.2, C6.1, C8.2, C9.1, C11.2, D8.2 (A), J7.1, J8.6, J8.9, J9.6, J14.1, R20.2, R23.1, R26.1, SW1.2, SW2.C, SW2.S2, U3.8 (GND), U3.22 (GND), U5.2 (A)
unnamed: D2.1 (K), R14.2
unnamed: D4.1 (K), R7.1
unnamed: D5.1 (K), R12.1
unnamed: D6.1 (K), R13.2
unnamed: D9.1 (K), R20.1
unnamed: J13.2, Q3.2 (D), R12.2
unnamed: Q4.3 (D), R15.1
unnamed: Q5.1 (G), Q6.1 (G), R24.2, R25.1
unnamed: Q5.3 (S), Q6.3 (S), R25.2
unnamed: Q7.3 (D), R24.1
unnamed: R5.2, R9.1, U4.2 (-)
unnamed: R2.1, R10.1, U4.3 (+)
unnamed: R2.2, R17.1, U1.1 (REF), U1.3 (K)
unnamed: R22.1, R23.2, U5.1 (REF)
VCC: C12.2, D4.2 (A), J15.2, U2.3 (OUT)

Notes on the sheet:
I2C header for display module
Bi-directional switch to fully isolate battery
RPi 12v MOSFET high-side switch
RPi ribbon connector
Reset Button
Board and RPi should be powered by BATT always in order to have un-interrupted power. The loads should be powered by SUPPLY supply when it is available, but switch to BATT when it is not available. CHARGER does not need a switch, it's always connected to BATT BATT needs a switch to take it on/off t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
5V regulation
Temperature sensor
Over-voltage protection
x40 gain, 2.4V offset
Current sensing 4-wire resistor
Voltage detector
User input

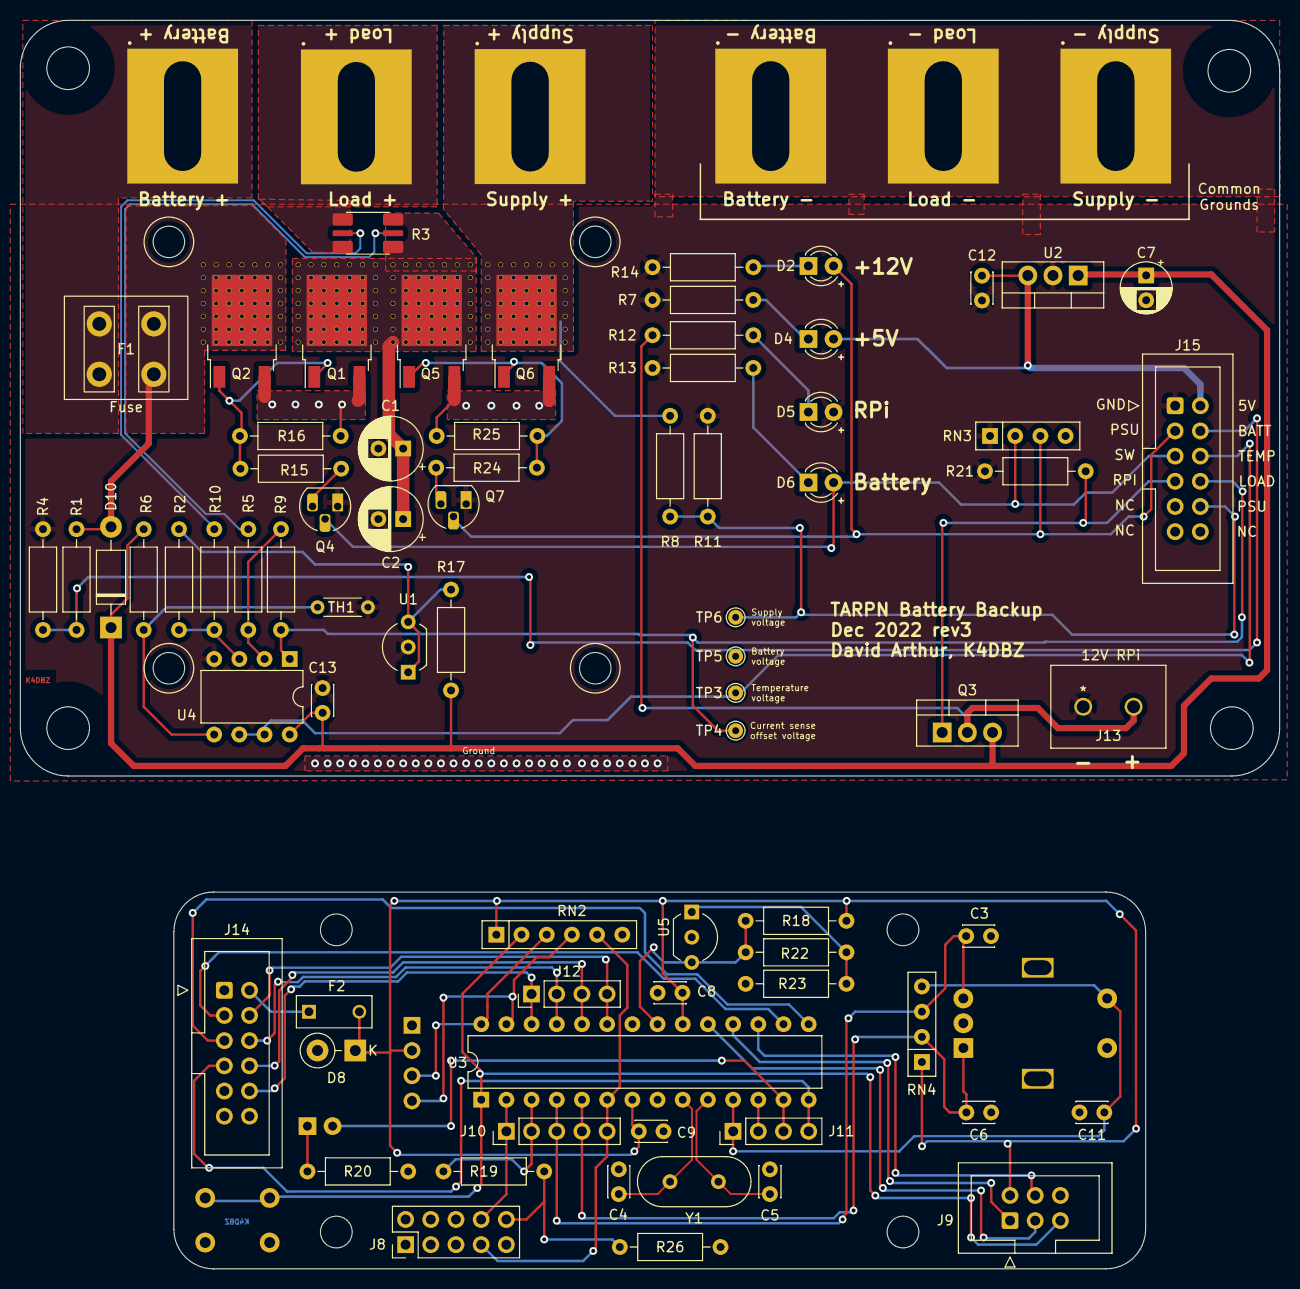
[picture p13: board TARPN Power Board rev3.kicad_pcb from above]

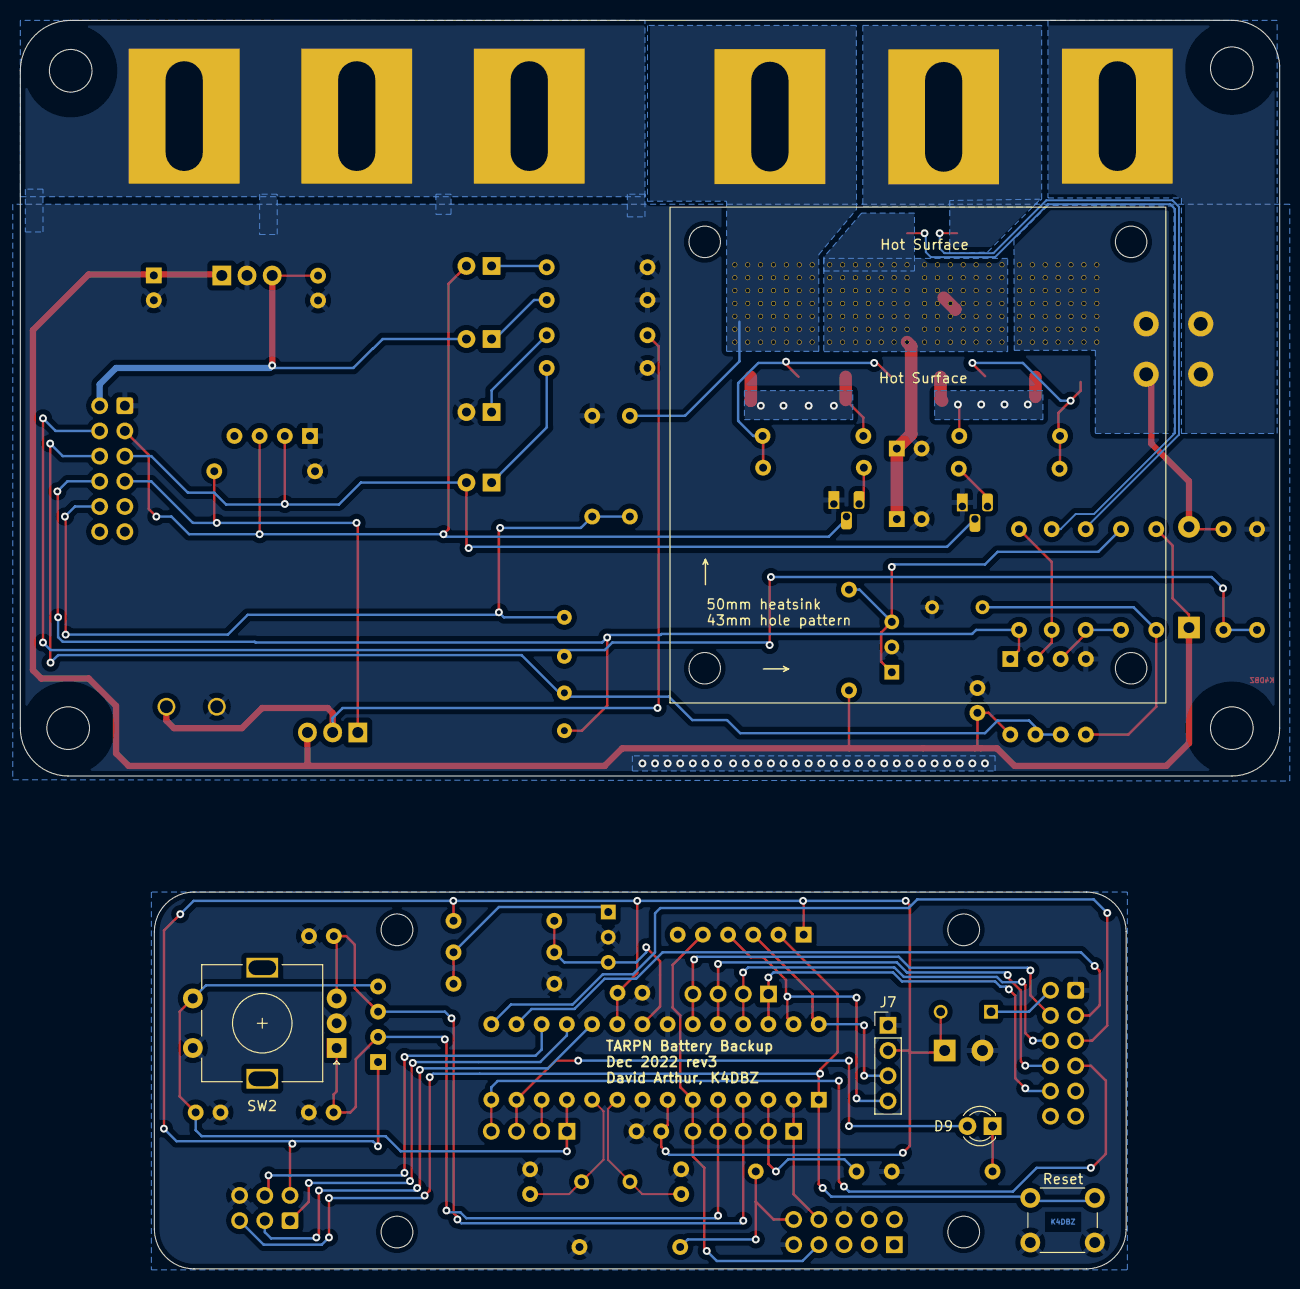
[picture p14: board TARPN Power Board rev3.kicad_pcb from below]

Board: 2 copper layers, 127.0 x 125.9 mm, 89 parts (4 on the bottom side), 62 nets.

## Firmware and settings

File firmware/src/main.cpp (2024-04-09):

#include <EEPROM.h>
#include <Arduino.h>
#include <Wire.h>
#include <Adafruit_SleepyDog.h>
#include <Bounce2.h>

#define ENCODER_OPTIMIZE_INTERRUPTS
#include <Encoder.h>
#define ENCODER_PIN_A 2
#define ENCODER_PIN_B 3

#include <LowPower.h>
#include <U8g2lib.h>

#include "config.h"
#include "voltage_read.h"
#include "ui.h"
#include "pid.h"
#include "free_memory.h"
#include "ser.h"
#include "rpi.h"
#include "metrics.h"
#include "batt.h"

#define RPI_POWEROFF_PIN 4  // pulled high, low, high when RPi is ready for power off 
#define STATUS_LED 7
#define RPI_PWR_PIN 8
#define BATTERY_PIN 5
#define SUPPLY_PIN 19
#define BUTTON_PIN 6

#define ADC_WARMUP_TIME_MS            2000    // Collect samples from the ADC for this long after startup
#define ADC_SAMPLE_INTERVAL_US         100    // How often to read from the ADC
#define SERIAL_BAUD_RATE             38400

#define STANDBY_LOW_VOLTAGE           12.5    // Below this PSU voltage, connect the battery
#define BATTERY_HIGH_VOLTAGE_CUTOFF   15.0    // At this voltage, disconnect the battery to protect loads
#define BATTERY_HIGH_VOLTAGE_RECOVERY 14.0    // At this voltage, reconnect the battery after high cutoff
#define BATTERY_LOW_VOLTAGE_CUTOFF    11.5    // At this voltage, disconnect the battery to protect battery
#define BATTERY_LOW_VOLTAGE_RECOVERY  12.0    // At this voltage, reconnect the battery after low cutoff
//#define BATTERY_LOW_VOLTAGE_SHUTDOWN  10.0    // At this voltage, the system will shutdown the RPI (TODO sleep?)
#define BATTERY_HIGH_VOLTAGE_TRIP_MS  10
#define BATTERY_LOW_VOLTAGE_TRIP_MS   3000
#define BATTERY_RECOVERY_MS           10000
#define OVER_TEMP_CUTOFF              60      // At this temperature in celsius, disconnect battery
#define OVER_TEMP_RECOVERY            50      // 
#define OVER_TEMP_RECOVERY_MS         10000   // 
#define BATTERY_FLOAT_VOLTAGE         12.5    // Default to a low float voltage so its disabled.

#define ABSOLUTE_MAX_VOLTAGE 18.0
#define ABSOLUTE_MAX_TEMP 100.0
//#define EEPROM_RESET 1

#define ADC_ZENER_VOLTAGE     4.90    // Measured from D1
#define VOLTAGE_FACTOR        0.267   // For 10k 27.4k resistor divider use 0.267.
#define VOLTAGE_OFFSET        0.000   // a fixed offset for voltages seen at ADC to account for signal path loss or ground offset
#define CURRENT_FACTOR        0.040   // Shunt resistor value times gain factor (0.002 * 20 = 0.04)
#define CURRENT_OFFSET        2.486   // Op amp uses a 2.4V reference to allow for negative voltages


struct StatefulConfigs {
  // Tunables
  float reference_voltage;
  float voltage_factor;
  float voltage_offset;
  float current_factor;
  float current_offset;
  float batt_current_factor;
  float batt_current_offset;
  // Configurables
  float standby_voltage;
  float batt_high_voltage_cutoff;
  float batt_high_voltage_recovery;
  float batt_high_voltage_trip_ms;
  float batt_low_voltage_cutoff;
  float batt_low_voltage_recovery;
  float batt_low_voltage_trip_ms;
  float batt_recovery_ms;
  float overtemp_cutoff;
  float overtemp_recovery;
  float overtemp_recovery_ms;
  float batt_float_voltage;
} config_defaults = {
  // Tunables
  ADC_ZENER_VOLTAGE, 
  VOLTAGE_FACTOR, 
  VOLTAGE_OFFSET,
  CURRENT_FACTOR, 
  CURRENT_OFFSET,
  CURRENT_FACTOR, 
  CURRENT_OFFSET,
  // Configurables
  STANDBY_LOW_VOLTAGE,
  BATTERY_HIGH_VOLTAGE_CUTOFF,
  BATTERY_HIGH_VOLTAGE_RECOVERY,
  BATTERY_HIGH_VOLTAGE_TRIP_MS,
  BATTERY_LOW_VOLTAGE_CUTOFF,
  BATTERY_LOW_VOLTAGE_RECOVERY,
  BATTERY_LOW_VOLTAGE_TRIP_MS,
  BATTERY_RECOVERY_MS,
  OVER_TEMP_CUTOFF,
  OVER_TEMP_RECOVERY,
  OVER_TEMP_RECOVERY_MS,
  BATTERY_FLOAT_VOLTAGE
};

StatefulConfigs configs;

enum State {
  Null,             // 0
  Initializing,     // 1
  Standby,          // 2
  Backup,           // 3
  Recovery,         // 4
  BatteryLow,       // 5
  BatteryLowTrip,   // 6
  BatteryHigh,      // 7
  BatteryHighTrip,  // 8
  OverTemp,         // 9
  OverTempRecovery, // 10
  BeginShutdown,    // 11
  ShutdownComplete, // 12
  SelfTest          // 13
};

const char state_0[] PROGMEM = "NULL";
const char state_1[] PROGMEM = "INIT";
const char state_2[] PROGMEM = "STANDBY";
const char state_3[] PROGMEM = "BACKUP";
const char state_4[] PROGMEM = "RECOVERY";
const char state_5[] PROGMEM = "BATT_LOW";
const char state_6[] PROGMEM = "BATT_LOW_TRIP";
const char state_7[] PROGMEM = "BATT_HIGH";
const char state_8[] PROGMEM = "BATT_HIGH_TRIP";
const char state_9[] PROGMEM = "OVER_TEMP";
const char state_10[] PROGMEM = "OVER_TEMP_RECOVER";
const char state_11[] PROGMEM = "BEGIN_SHUTDOWN";
const char state_12[] PROGMEM = "SHUTDOWN_COMPLETE";
const char state_13[] PROGMEM = "SELF_TEST";

const char* const states[] PROGMEM = {
  state_0, state_1, state_2, state_3, state_4, state_5,
  state_6, state_7, state_8, state_9, state_10, state_11, 
  state_12, state_13
};

char label_buffer[16];

PID pid_cc;
PID pid_cv;
PID * pid = &pid_cc; // points to the active PID

float ONE = 1.0;

SensorRead batteryVoltage;
SensorRead supplyVoltage;
SensorRead tempSense;
SensorRead currentSense;
SensorRead chargeSense;

/**
 * A nicely packed structure for storing the configurations in the EEPROM.
 * All values are scaled up by 1000 (except timing values) and stored as 16-bit unsigned ints.
 */
struct PackedConfig {
  // v1
  uint16_t reference_voltage;
  uint16_t voltage_factor;
  uint16_t current_factor;
  uint16_t current_offset;  
  uint16_t standby_voltage;
  uint16_t batt_high_voltage_cutoff;
  uint16_t batt_high_voltage_recovery;
  uint16_t batt_high_voltage_trip_ms;
  uint16_t batt_low_voltage_cutoff;
  uint16_t batt_low_voltage_recovery;
  uint16_t batt_low_voltage_trip_ms;
  uint16_t batt_recovery_ms;
  uint16_t overtemp_cutoff;
  uint16_t overtemp_recovery;
  uint16_t overtemp_recovery_ms;
  // v2
  int16_t voltage_offset;   // Signed int because we can have negative offset
  // v3
  uint16_t batt_float_voltage;
  // v4
  uint16_t batt_current_factor;
  uint16_t batt_current_offset; 
};

#define LATEST_EEPROM_VERSION 4

void toPackedConfig(StatefulConfigs * configs, PackedConfig * packed) {
  packed->reference_voltage = configs->reference_voltage * 1000;
  packed->voltage_factor = configs->voltage_factor * 1000;
  packed->current_factor = configs->current_factor * 1000;
  packed->current_offset = configs->current_offset * 1000;
  packed->standby_voltage = configs->standby_voltage * 1000;
  packed->batt_high_voltage_cutoff = configs->batt_high_voltage_cutoff * 1000;
  packed->batt_high_voltage_recovery = configs->batt_high_voltage_recovery * 1000;
  packed->batt_high_voltage_trip_ms = configs->batt_high_voltage_trip_ms;
  packed->batt_low_voltage_cutoff = configs->batt_low_voltage_cutoff * 1000;
  packed->batt_low_voltage_recovery = configs->batt_low_voltage_recovery * 1000;
  packed->batt_low_voltage_trip_ms = configs->batt_low_voltage_trip_ms;
  packed->batt_recovery_ms = configs->batt_recovery_ms;
  packed->overtemp_cutoff = configs->overtemp_cutoff;
  packed->overtemp_recovery = configs->overtemp_recovery;
  packed->overtemp_recovery_ms = configs->overtemp_recovery_ms;
  // v2
  packed->voltage_offset = configs->voltage_offset * 1000;
  // v3
  packed->batt_float_voltage = configs->batt_float_voltage * 1000;
  // v4
  packed->batt_current_factor = configs->batt_current_factor * 1000;
  packed->batt_current_offset = configs->batt_current_offset * 1000;
}

void fromPackedConfig(uint8_t version, StatefulConfigs * configs, PackedConfig * packed) {
  // v4
  if (version > 3) {
    configs->batt_current_factor = packed->batt_current_factor / 1000.0;
    configs->batt_current_offset = packed->batt_current_offset / 1000.0;
  } else {
    configs->batt_current_factor = config_defaults.batt_current_factor;
    configs->batt_current_offset = config_defaults.batt_current_offset;
  }
  
  // v3
  if (version > 2) {
    configs->batt_float_voltage = packed->batt_float_voltage / 1000.0;
  } else {
    configs->batt_float_voltage = config_defaults.batt_float_voltage;
  }
  
  // v2
  if (version > 1) {
    configs->voltage_offset = packed->voltage_offset / 1000.0;
  } else {
    configs->voltage_offset = config_defaults.voltage_offset;
  }
  
  if (version > 0) {
    // v1
    configs->reference_voltage = packed->reference_voltage / 1000.0;
    configs->voltage_factor = packed->voltage_factor / 1000.0;
    configs->current_factor = packed->current_factor / 1000.0;
    configs->current_offset = packed->current_offset / 1000.0;
    configs->standby_voltage = packed->standby_voltage / 1000.0;
    configs->batt_high_voltage_cutoff = min(ABSOLUTE_MAX_VOLTAGE, packed->batt_high_voltage_cutoff / 1000.0);
    configs->batt_high_voltage_recovery = packed->batt_high_voltage_recovery / 1000.0;
    configs->batt_high_voltage_trip_ms = packed->batt_high_voltage_trip_ms;
    configs->batt_low_voltage_cutoff = packed->batt_low_voltage_cutoff / 1000.0;
    configs->batt_low_voltage_recovery = packed->batt_low_voltage_recovery / 1000.0;
    configs->batt_low_voltage_trip_ms = packed->batt_low_voltage_trip_ms;
    configs->batt_recovery_ms = packed->batt_recovery_ms;
    configs->overtemp_cutoff = min(ABSOLUTE_MAX_TEMP, packed->overtemp_cutoff);
    configs->overtemp_recovery = packed->overtemp_recovery;
    configs->overtemp_recovery_ms = packed->overtemp_recovery_ms;
  }
}

void save_config() {
  PackedConfig to_store;
  toPackedConfig(&configs, &to_store);
  EEPROM.put(0x00, LATEST_EEPROM_VERSION);
  EEPROM.put(0x01, to_store);
}

void reset_config() {
  // Zero out everything
  for (uint16_t i = 0 ; i < EEPROM.length() ; i++) {
    EEPROM.update(i, 0);
  }
  // replace it with the defaults
  EEPROM.put(0x00, LATEST_EEPROM_VERSION);
  PackedConfig to_store;
  toPackedConfig(&config_defaults, &to_store);
  EEPROM.put(0x01, to_store);
}

void load_config() {
  PackedConfig packed;
  uint8_t version = EEPROM.read(0x00);
  EEPROM.get(0x01, packed);
  fromPackedConfig(version, &configs, &packed);
}

unsigned long start_time;
State state = Initializing;
unsigned long last_state_change;
double temperature;
unsigned long last_adc_read;
unsigned long last_serial_write;
unsigned long last_serial_read;
unsigned long last_heartbeat;
bool bpq_running;

uint32_t self_test_ms = 0;

Encoder myEnc(ENCODER_PIN_A, ENCODER_PIN_B);
int last_encoder_pos = 0;
Bounce user_sw;

U8G2_SSD1309_128X64_NONAME0_2_4W_HW_SPI u8g2(U8G2_R0, 10, 9);

Metrics metrics;
MetricsReport report;
RPi rpi;
ChargeState charger;

void RPi_Init(RPi * rpi) {
  rpi->state = RPI_POWERED_ON;
  rpi->switch_state = LOW;
  rpi->rpi_poweroff_active = false;
}

void RPi_Shutdown(RPi * rpi, unsigned long now) {
  Serial.println(F("EVENT SHUTDOWN_RPI"));
  rpi->last_state_change = now;
  rpi->state = RPI_SHUTDOWN_EVENT_SENT;
}

void RPi_Update(RPi * rpi, unsigned long now) {
  // poweroff pin is low when the RPi is powered off. 
  // It transitions low, high, low during poweroff
  rpi->rpi_poweroff_active = digitalRead(RPI_POWEROFF_PIN) == LOW;

  RPiShutdownState newState = rpi->state;
  switch (rpi->state) {
    case RPI_POWERED_ON:
      rpi->switch_state = LOW;
      if (rpi->rpi_poweroff_active) {
        newState = RPI_KEEPALIVE_POWEROFF_SEEN;
      }
      break;
    case RPI_KEEPALIVE_POWEROFF_SEEN:
      if ((now - rpi->last_state_change) > 3000) {
        newState = RPI_KEEPALIVE_POWERED_OFF;
      }
      break;
    case RPI_KEEPALIVE_POWERED_OFF:
      rpi->switch_state = HIGH;
      if ((now - rpi->last_state_change) > 60000) {
        newState = RPI_KEEPALIVE_POWERED_ON;
      }
      break;
    case RPI_KEEPALIVE_POWERED_ON:
      rpi->switch_state = LOW;
      // Wait for poweroff signal to go away
      if ((now - rpi->last_state_change) > 3000 && !rpi->rpi_poweroff_active) {
        newState = RPI_POWERED_ON;
      }
      break;
    case RPI_SHUTDOWN_EVENT_SENT:
      if (rpi->rpi_poweroff_active) {
        newState = RPI_SHUTDOWN_POWEROFF_SEEN;
      }
      // After 1 minute, give up and go back to default state
      if ((now - rpi->last_state_change) > 60000) {
        newState = RPI_POWERED_ON;
      }
      break;
    case RPI_SHUTDOWN_POWEROFF_SEEN:
      if ((now - rpi->last_state_change) > 3000) {
        newState = RPI_SHUTDOWN_POWERED_OFF;
      }
      break;
    case RPI_SHUTDOWN_POWERED_OFF:
      rpi->switch_state = HIGH;
      break;
  }
  if (newState != rpi->state) {
    rpi->state = newState;
    rpi->last_state_change = now;
  }
}

/**
 * Calculate the temperature using Steinhart–Hart equation. A 49.9k resistor and 10k NTC thermistor are hard coded here.
 */
double calculate_temp() {
  // We still use the EMWA filter in VoltageRead, but calculate the real value here.
  double res = (49900.0 * Sensor_adcVoltageFast(&tempSense)) / (Sensor_smoothedValueFast(&batteryVoltage) - Sensor_adcVoltageFast(&tempSense));
  double steinhart = logf(res / 10000.0);
  steinhart /= 3933;
  steinhart += (1.0 / 298.15);
  steinhart = 1.0 / steinhart;
  steinhart -= 273.15;
  return steinhart;
}

/*******************************************************************************
 *                                                                             *
 *                                 State Machine                               *
 *                                                                             *
 *******************************************************************************/
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
void loop() {
  unsigned long now = millis();
  last_now = now;

  // Evaluate the state machine and change the output state
  boolean changed_state = next_state(now, temperature, &ui);
  apply_state(now, state);
  if (changed_state) {
    send_state_change_event(now);
    last_serial_write = now;
  }

  // Only enter low power mode if we're not headless
  if (state == ShutdownComplete && !ui.headless_debug_mode_enabled) {
    // Low power mode will mess with millis(). The ShutdownComplete state ignores time
    // and only considers the instantaneous value of the ADC for the battery voltage.
    LowPower.powerDown(SLEEP_8S, ADC_OFF, BOD_OFF);

    // Flash the status LED so users know we're alive
    digitalWrite(STATUS_LED, HIGH); 
    delay(50);
    digitalWrite(STATUS_LED, LOW);
    
    // After one sleep, clear the display
    //display.clearDisplay();
    //display.display();
    //display.dim(true);
    u8g2.clearDisplay();
    //u8g2.setPowerSave(1);

    // Read the battery voltage to give us a chance to wakeup
    //read_voltage(A0, &batteryVoltage, time_us);
    return;
  }

  
  // Only read the ADCs every so often
  unsigned long dt = now - last_adc_read;
  if (dt > 100) {
    temperature = calculate_temp();
    double elapsed_sec = dt / 1000.;
    Metrics_Update(&metrics, elapsed_sec);
    double chargeVoltage = Sensor_smoothedValueFast(&batteryVoltage);
    double chargeCurrent = Sensor_smoothedValueFast(&chargeSense);

    switch (charger.state) {
      case CHARGE_INIT:
        if ((now - charger.state_ms) > MIN_CHARGE_STATE_MS) { // TODO increase this to some minutes
          charger.state = CHARGE_CC;
          charger.state_ms = now;
          pid = &pid_cc;
        }
        break;
      case CHARGE_CC:
        if ((now - charger.state_ms) > MIN_CHARGE_STATE_MS && (chargeVoltage - configs.batt_float_voltage) > 0.01) {
          charger.state = CHARGE_CC_HOLD;
          charger.state_ms = now;
          //pid_cv.pid_output = pid_cc.pid_output;
        }
        PID_Update(&pid_cc, dt, 1.0, -1.0 * chargeCurrent);
        break;
      case CHARGE_CC_HOLD:
        if ((now - charger.state_ms) > MIN_CHARGE_STATE_MS) {
          charger.state = CHARGE_CV;
          charger.state_ms = now;
          pid = &pid_cv;
          pid_cv.pid_output = pid_cc.pid_output;
        }
        //PID_Update(&pid_cc, now, 1.0, -1.0 * chargeCurrent);
        //PID_Update(&pid_cv, now, configs.batt_float_voltage, chargeVoltage);
        break;
      case CHARGE_CV:
        // Just trickle charge forever
        PID_Update(&pid_cv, dt, configs.batt_float_voltage, chargeVoltage);
        break;   
      case CHARGE_OFF:
      default:
        pid_cc.pid_output = 0.0;
        pid_cv.pid_output = 0.0;
        if ((now - charger.state_ms) > MIN_CHARGE_STATE_MS && state == Standby) {
          if (configs.batt_float_voltage > chargeVoltage) {
            charger.state = CHARGE_INIT;
            charger.state_ms = now;
          }
        }
        break;
    }

    RPi_Update(&rpi, now);
    last_adc_read = now;
  }

  if ((now - last_serial_read) > 200) {
    read_serial(now);
    last_serial_read = now;
  }

  // Output to Serial occasionally
  if ((now - last_serial_write) > 2000) {
    Metrics_Report(&metrics, now);
    send_serial_data(metrics.report, now);
    ui_us = 0;
    last_serial_write = now;
  }

  // Read from the encoder
  UI_encoder_position(&ui, now, myEnc.read());
  //user_sw.update();
  //if (user_sw.rose()) {
  //  UI_encoder_button_press(&ui, now);
  //}

  // Handle any user event
  UserEvent event = UI_next_event(&ui, now);

  // Choose a display mode
  if (event != NONE || (now - ui.last_display_update_ms) > 500) {
    if (ui.config_mode_enabled) {
      display_config(&ui, now, event);
    } else {
      display_main(&ui, now, event);
    }
    ui.last_display_update_ms = now;
  }
}

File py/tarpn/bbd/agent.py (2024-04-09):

import argparse
import configparser
import dataclasses
import logging
import logging.config
import os
import queue
import shutil
import signal
import struct
import subprocess
import time
from datetime import datetime
from io import BytesIO
from typing import Dict, Callable

from prometheus_client import Counter, Gauge, Enum, Info, start_http_server

from tarpn.bbd.unix import AgentSocketProtocol, UnixServerThread
from tarpn.io import IOProtocol
from tarpn.io.serial import SerialDevice
from tarpn.logging import LoggingMixin, TRACE
from tarpn.thread.ring import RingBuffer
from tarpn.thread.scheduler import CloseableThreadLoop, Scheduler

from tarpn.bbd import __version__
from tarpn.bbd.spec import Parser, ParsedBBDLine, BBDState, BBDChargeState, BBDParseException

logger = logging.getLogger('root')

state_enum = Enum("board_state", "The internal state of the board", states=[
    "Null","Initializing","Standby","Backup","Recovery","BatteryLow",
    "BatteryLowTrip","BatteryHigh","BatteryHighTrip","OverTemp",
    "OverTempRecovery", "BeginShutdown", "RPiShutdown", "ShutdownComplete",
    "SelfTest"
])

charge_state_enum = Enum("batt_charge_state", "The status of the battery charger", states=[
    "Off", "Init", "CC", "Hold", "CV"
])


max_amps = None
min_amps = None

last_update_time = time.time()


@dataclasses.dataclass
class AgentEvent:
    pass


@dataclasses.dataclass
class AgentStartupEvent:
    pass


@dataclasses.dataclass
class AgentHeartbeat(AgentEvent):
    pass


@dataclasses.dataclass
class AgentSendIP(AgentEvent):
    pass


@dataclasses.dataclass
class BBDEvent(AgentEvent):
    event_type: str
    event_data: Dict[str, str]


@dataclasses.dataclass
class BBDData(AgentEvent):
    data: ParsedBBDLine


@dataclasses.dataclass
class BBDLog(AgentEvent):
    msg: str


@dataclasses.dataclass
class BBDConfig(AgentEvent):
    key: str
    value: str


@dataclasses.dataclass
class UnixSocketEvent(AgentEvent):
    msg: str


class BBDSerialProtocol(IOProtocol, Parser):
    def __init__(self, hardware_version: int, callback: Callable[[AgentEvent], None]):
        self.out_queue: RingBuffer[bytes] = RingBuffer(4)
        self.buffer = bytearray()
        self.callback: Callable[[AgentEvent], None] = callback
        self.hardware_version = hardware_version

    def send_to_bbd(self, data: bytes):
        self.out_queue.offer(data)

    # IOProtocol
    def handle_bytes(self, data: bytes) -> None:
        for b in data:
            self.buffer.append(b)
            if self.buffer.endswith(b"\r\n"):
                try:
                    self.parse(self.buffer, self.hardware_version)
                except BBDParseException:
                    logger.error(f"Could not parse buffer: {self.buffer}", )
                except Exception:
                    logger.error(f"Had an error while parsing buffer: {self.buffer}", )
                self.buffer.clear()

    def next_bytes_to_write(self, max_bytes: int) -> bytes:
        item, dropped = self.out_queue.take(timeout=0.100)  # Don't wait too long here, this blocks
        if item is not None:
            return item + b'\r\n'

    # Parser
    def handle_line(self, line: ParsedBBDLine):
        self.callback(BBDData(line))

    def handle_log(self, log: str):
        self.callback(BBDLog(log))

    def handle_event(self, event_type: str, data: Dict[str, str]):
        self.callback(BBDEvent(event_type, data))

    def handle_config(self, key: str, value: str):
        self.callback(BBDConfig(key, value))


class BBDAgentThread(CloseableThreadLoop, LoggingMixin):
    def __init__(self,
                 event_queue: queue.Queue,
                 unix_client: AgentSocketProtocol,
                 bbd_writer: Callable[[bytes], None],
                 enable_shutdown: bool,
                 hardware_version: int):
        CloseableThreadLoop.__init__(self, "agent")
        LoggingMixin.__init__(self, logging.getLogger("agent"))
        self.unix_client = unix_client
        self.bbd_writer = bbd_writer
        self.event_queue = event_queue
        self.enable_shutdown = enable_shutdown
        self.hardware_version = hardware_version
        self.event_queue.put(AgentStartupEvent())
        self.last_heartbeat = datetime.utcnow()
        self.first_bbd_line = True

    def enqueue_event(self, event: AgentEvent):
        self.event_queue.put(event)

    def deadline_sec(self, now: datetime) -> float:
        dt = (now - self.last_heartbeat).total_seconds()
        if dt > 3.0:
            self.event_queue.put(AgentHeartbeat())
            return 0.0
        else:
            return dt

    def iter_loop(self):
        now = datetime.utcnow()
        deadline = self.deadline_sec(now)
        event = None
        try:
            event = self.event_queue.get(timeout=deadline)
        except queue.Empty:
            pass

        if event is not None:
            self.debug(f"Processing event {event}")
            if isinstance(event, AgentStartupEvent):
                self.bbd_writer(b"P 1 Agent Start")
                self.event_queue.put(AgentSendIP())
            elif isinstance(event, AgentHeartbeat):
                self.bbd_writer(b"H")
                self.last_heartbeat = now
            elif isinstance(event, AgentSendIP):
                self.bbd_writer(b"P 2 Update IP")
                ip = get_local_ip()
                self.bbd_writer(build_net_message(ip))
            elif isinstance(event, BBDEvent):
                self.handle_bbd_event(event.event_type, event.event_data)
            elif isinstance(event, BBDLog):
                self.info(f"Log from firmware: {event.msg}")
                self.unix_client.send_if_connected(event.msg)
            elif isinstance(event, BBDConfig):
                self.info(f"Config change from firmware: {event.key} = {event.value}")
                self.unix_client.send_if_connected(f"CONFIG {event.key} {event.value}")
            elif isinstance(event, BBDData):
                self.handle_bbd_data(event.data)
            elif isinstance(event, UnixSocketEvent):
                self.handle_unix_socket_data(event.msg)
            else:
                self.warning(f"Ignoring unknown event with unknown type {event}")

    def handle_bbd_event(self, event_type: str, event_data: Dict[str, str]):
        self.info(f"Event from firmware: {event_type} {event_data}")
        self.unix_client.send_if_connected(f"EVENT {event_type} {event_data}")

        if event_type == "STARTUP":
            board_build_info.info(event_data)
            self.event_queue.put(AgentSendIP())
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

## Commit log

2024-04-09 Prepare repository for public
    [TARPN Power Board rev3.kicad_pcb, TARPN Power Board rev3.kicad_sch]
2024-04-11 add STL for terminal guard
    [TerminalGuard.stl]
2024-06-14 make firmware device configurable
